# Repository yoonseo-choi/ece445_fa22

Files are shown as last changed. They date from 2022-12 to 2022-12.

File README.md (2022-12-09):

# ECE 445 Fall 2022 - Team 23

**Team Members**
- Yoonseo Choi (yschoi4)
- Aaron Gros (aygros2)
- Sean Kim (sk5)

**Lateral Movement Force-Feedback VR Gloves**

We have created a low-cost and open source force-feedback VR glove for lateral finger movement. It is able to acurate track and restrict the index, middle, ring, and pinky finger.

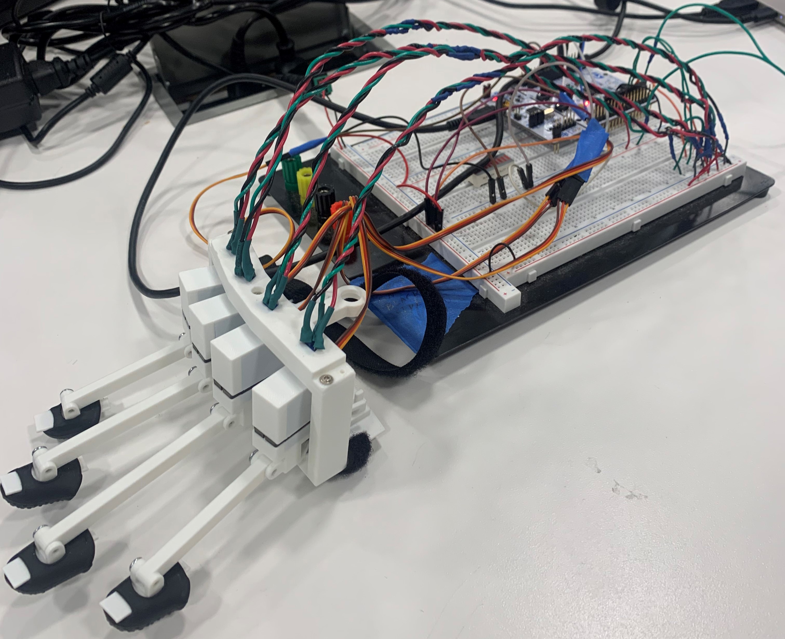
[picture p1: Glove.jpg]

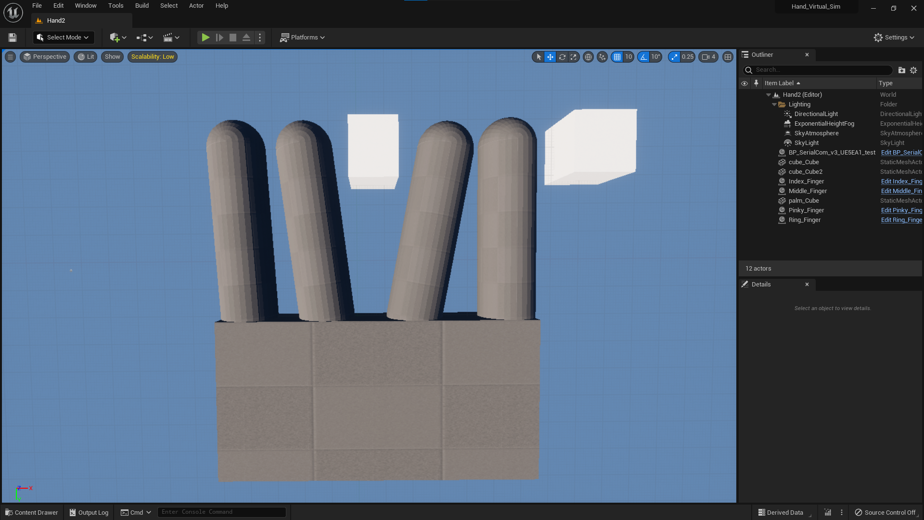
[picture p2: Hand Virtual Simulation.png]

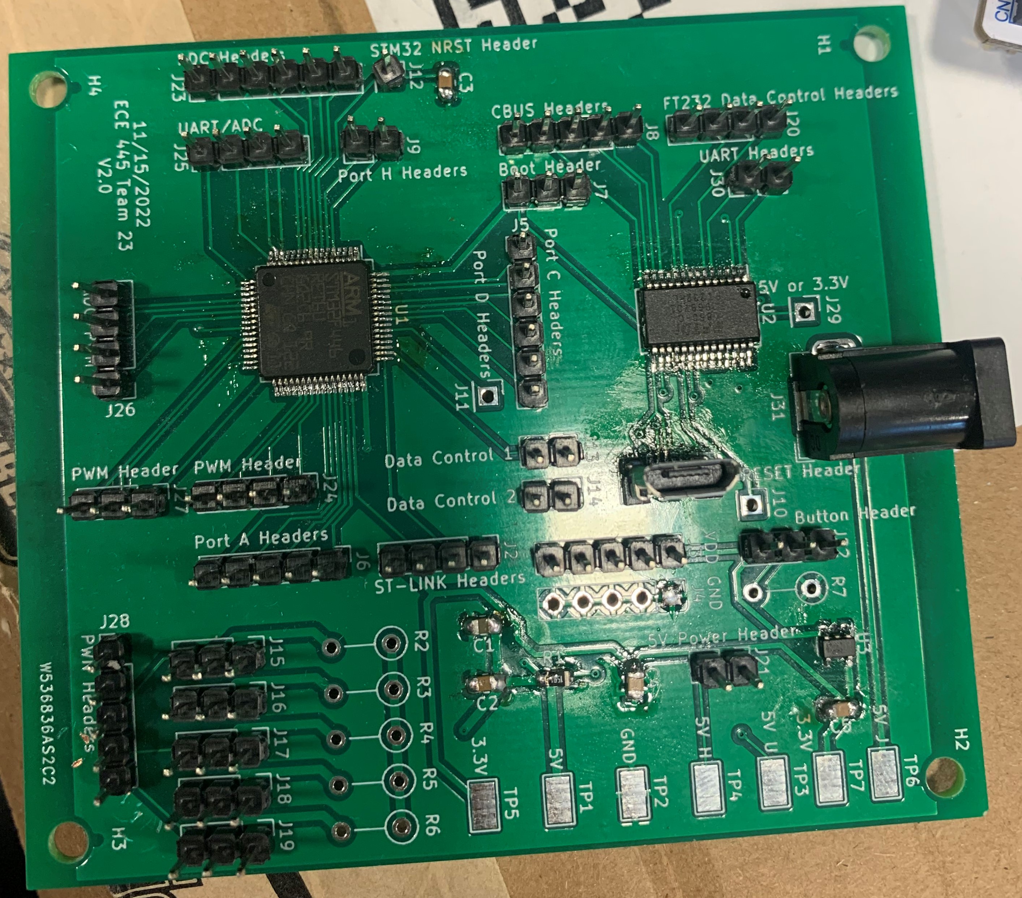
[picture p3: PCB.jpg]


**Google Drive Repository** 
[Google Repo Link](https://drive.google.com/drive/folders/11H3rUvDkAtsJpdgwuR88esnsnRXGqsm2?usp=sharing)

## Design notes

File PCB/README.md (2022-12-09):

# PCB 

**PCB Design for VR Glove**

This branch contains all files and folders related tothe pcb layout and design of the VR glove.

**Basic Git Commands**

1. git checkout pcb ; for switching into pcb branch

2. git pull ; get updated version of remote repo

3a. git add {whatever file you want to add} ; adds specific files

3b. git add . ; this adds all the changes you made

4. git commit -m "{whatever message}"

5. git push ; to update the remote repo

git status ; to check status of branch

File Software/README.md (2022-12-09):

Only uploaded the project content since the entire unreal engine project was too large. If you want to run this you need unreal engine 5.0.3 and you'll need this plugin: https://github.com/videofeedback/Unreal_Engine_SerialCOM_Plugin/. You'll have to create a project, import all the content and insert it into the scene. The colision option may reset so you may need to set the colision option for the fingers to BlockAllDynamic.

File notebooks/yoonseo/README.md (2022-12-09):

# Yoonseo's Notebook

**09-27-2022: Part Selection and Firmware Brainstorming**  

Decided on using servo motors for lateral movement feedback. 
Design is up for 2 options:
- Fixed pole and rotating restriction prongs
- Rotating (Side-to-Side) pole and fixed restriction prongs

Updated firmware data processing and control algorithm flowchart.

Ordered Stm32 MCU

**10-04-2022 PCB Design Parts 1**

Decided on Micro-USB, ST-Link, FTDI Parts

Started crafting the PCB design after design review today

Design review critiques:
- Tolerance Analysis: more specific with angle precision (data value count / rotation angle degree)
- Safety: Be cautious about the servo motor torque on finger and show calculations assuring its safety.

Need to decide if we want to use CTS and RTS flow control scheme for FTDI <-> STM32 MCU

**10-08-2022: PCB Design Parts 2**

Completed the micro usb module that functions as power and usb data communication (still need to annotate fuse value)

Added basic connections for both STM32 and FT232 chip
- STM32: figure out how to use connectors on pin PA13,14 for SWD ST-Link Programmer
- FT232: Need to decide how to route other pins (i.e. NRESET, CTS, RTS, etc) and add male connectors to GND and VDD

**10-14-2022: Parts Ordering**

Completed a list of the project's BOM and started ordering the physical parts for the PCB.

Initiated a project folder on STM32 Cube IDE for the development of STM32F446RE firmware

**10-22-2022: Stm32 Development Board Testing**

Before moving everything over to our PCB, we decided to develop and test all of our firmware features on the STM32F446RE development board

Spent much time on the MCU documentation learning the specifications of the ADC channels, PWM timers, and UART communication protocols. 

Some setbacks:
- Assigning pins for each of the modules proved to be challenging since I had to make sure the pins I was using did not overlap in functionality of other relevant functionalities. 
- Setting an appropriate clock configuration (fast enough clock speed)

**10-29-2022: PCB v1.0 Order & Dev Board UART Configuration**

Made final changes to the PCB v1.0 order.

Aside from that, I continued my work on the firmware, specifically on the UART. 

All code I used for this project relied on the given HAL libraries. To see if I was sending the correct data to the PC, I configured the minicom serial monitor on my computer (running on Ubuntu) so that the HAL_UART function printed to the console.

**11-07-2022: PCB v2 Start & ADC Channel Configuration**

For our PCB v1.0, we realized a crucial mistake: not recognizing the correct operating voltage of MCU. 

Essentially, we fed 5V into a 3.3V system. Consequently, we fried our MCU, and since it took over a month for it to arrive, we decided that ordering another STM32 (from china) would be pointless given the current lead time.

To address this problem, and some other power problems, we determined using a higher power rating wall plug and a 5-3.3V Linear Converter would be new additions for our next PCB.

As for the firmware, I was able to start development for the ADC channels in order to sample the potentiometer voltage values from the finger movements. 

ADC Configuration Challenges:
- Needed to prioritize order of channel sampling and sending them to pc via uart
- Decided to utilize DMA mode for ADC for more efficient CPU cycle use

**11-12-2022: PWM Timer Configurations**

The servos we ordered required specific pwm signals to rotate certain angles.

When setting the configurations for PWM, there were many calculation to be made and setting/modifying control register to specific values.

PWM Timer Register Configuration

[Servo Motor Data Sheet](../../MG90S_Tower-Pro.pdf)

**11-13-2022: PCB Soldering and Firmware Algorithm Development**

Our parts for the PCB arrived, so we soldered on all of our parts except the STM32. At this point, since we only had the MCU on the dev board, we determined that waiting to place the MCU on the custom PCB after testing the firmware to its full functionality would be the optimal decision.

Hands down, the hardest part about the algorithm development was determining the correct pulse to send to the servo and the angle it should turn to accurately restrict the finger movement of the user. 

This session aimed to mostly cover the moving of the servos to the desired angle and create functions to do so. 

**11-25-2022: FW Algorithm Testing and SW Integration**

After thanksgiving, I was able to finish the initial firmware draft and start testing the actual glove with different stimuli. After I was able to verify some of the controls requirements for our project, I started to create a standard data format where to get ready for the graphics platform to communicate under a similar data scheme with the firmware.

Out Data: (16 bytes) 4 bytes for each finger position
In Data: (4 bytes) 1 byte for each finger using 2 bit representation
- '0'(00): no collision
- '1'(01): right collision
- '2'(10): left collision
- '3'(11): both collisions

We made videos of the project successfully performing requirements set, then soldered the STM32 onto the custom PCB

**12-01-2022: Final Demo Review**

Our last meeting for the development process was making sure we had all the verification for our requirements, rubrics printed out for the demo, and last minute checklist run down. Although we weren't able to demo today with our actual product (because the custom PCB didn't work), we were able to show videos of the working glove. It was a huge regret not being able to showcase what I've worked on the whole semester with so much time and effort, but it proved to be a valuable lesson where it taught me that there are always priorities and when you run into a dilemma, choosing one way will always have some consequences for not choosing the other, but you still need to make the best out of it and weigh your pros and cons before settling on a single decision.

Overall, this project taught me many things about not just the firmware development of the STM32 but also time management, project insight, team communication, etc. It'll be skills I'll continue to develop throughout my career.

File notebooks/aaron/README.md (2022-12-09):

10/17/2022

**Objective:** Get started 3d modeling all the pieces

**Accomplished:** Designed a base that stays in place on one’s hand with velcro straps. It also had bearing holders and stopping pins. I got a 3d model of the servo we’re using online. I made a model for our bearing and potentiometer based on dimensions I found where I ordered them. I made two pieces that go on the top and bottom of the servo and attach to bearings. I designed a piece with bearing holders that attaches to the base and holds the servo in place. I designed a piece that goes over the previous piece and holds the potentiometers. I made an extension to the servo arm that interacts with the stopping pin.

<p float="left">
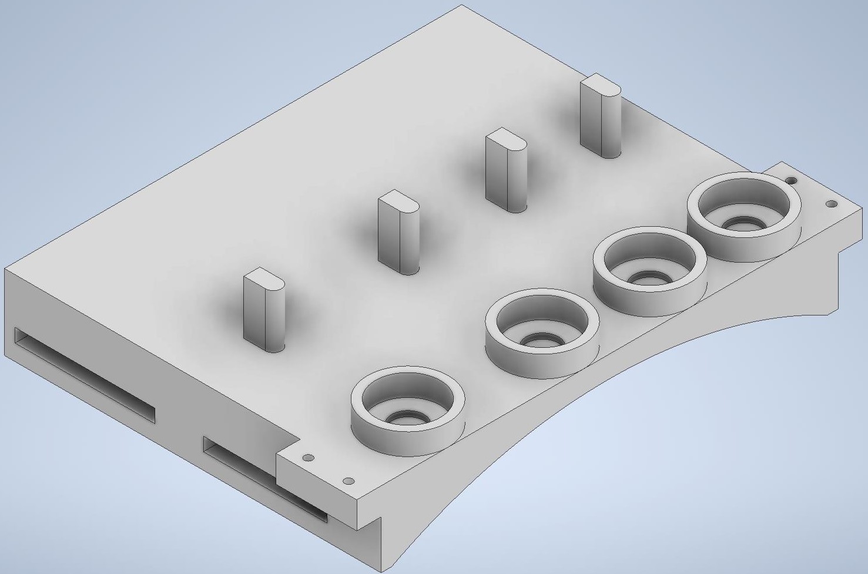
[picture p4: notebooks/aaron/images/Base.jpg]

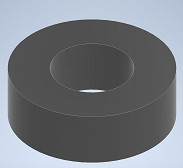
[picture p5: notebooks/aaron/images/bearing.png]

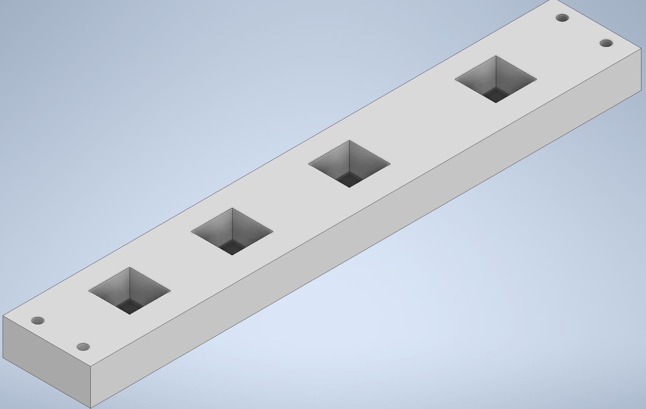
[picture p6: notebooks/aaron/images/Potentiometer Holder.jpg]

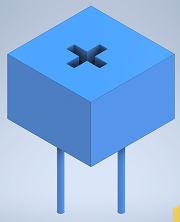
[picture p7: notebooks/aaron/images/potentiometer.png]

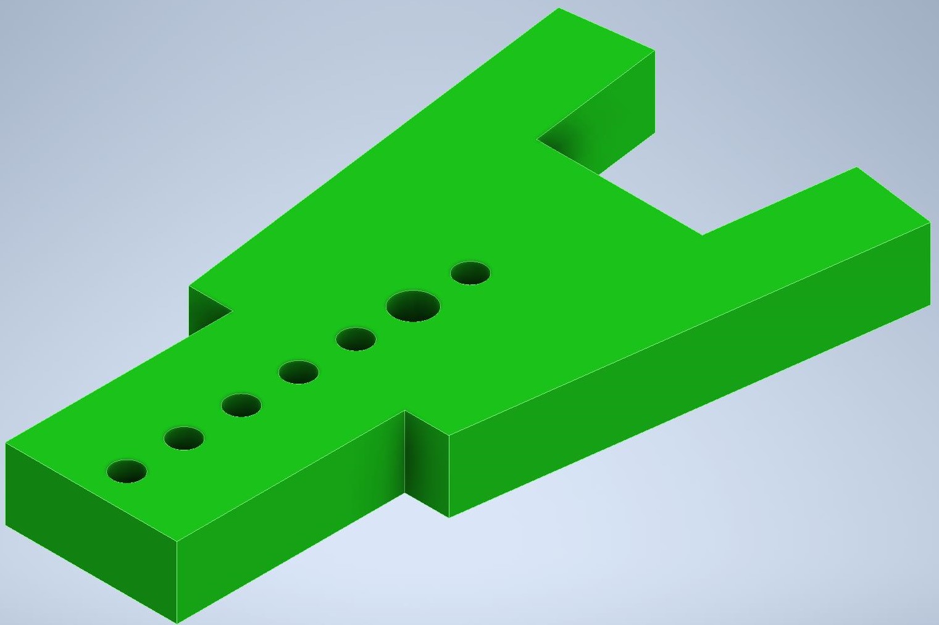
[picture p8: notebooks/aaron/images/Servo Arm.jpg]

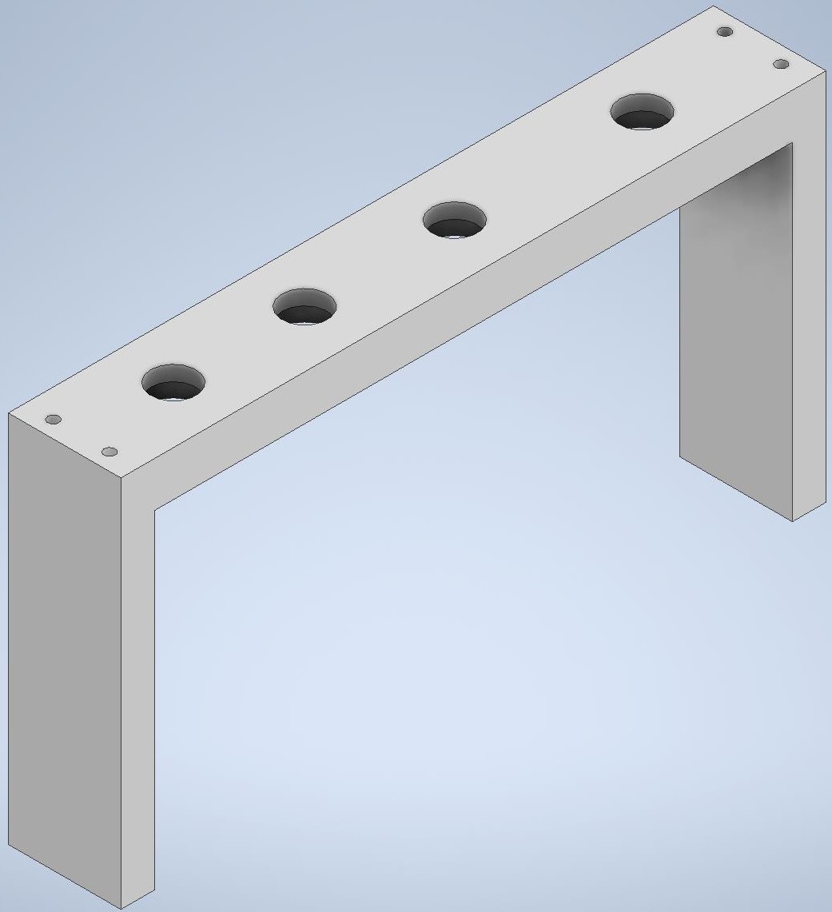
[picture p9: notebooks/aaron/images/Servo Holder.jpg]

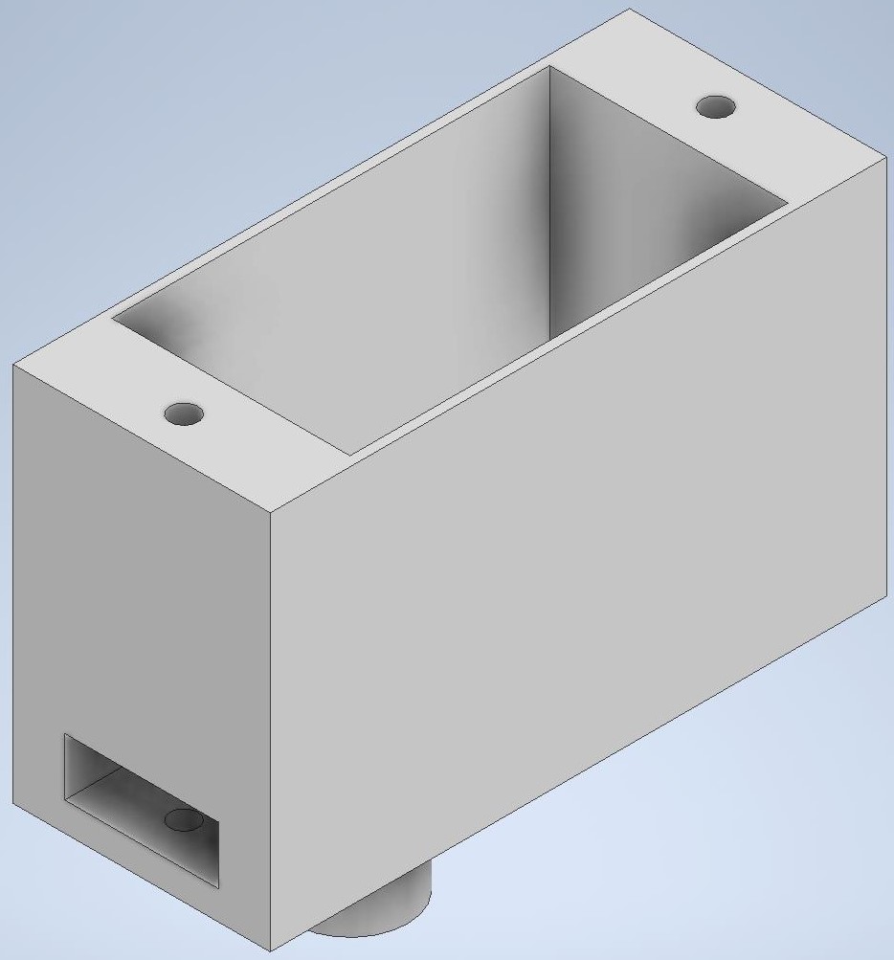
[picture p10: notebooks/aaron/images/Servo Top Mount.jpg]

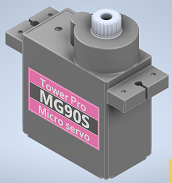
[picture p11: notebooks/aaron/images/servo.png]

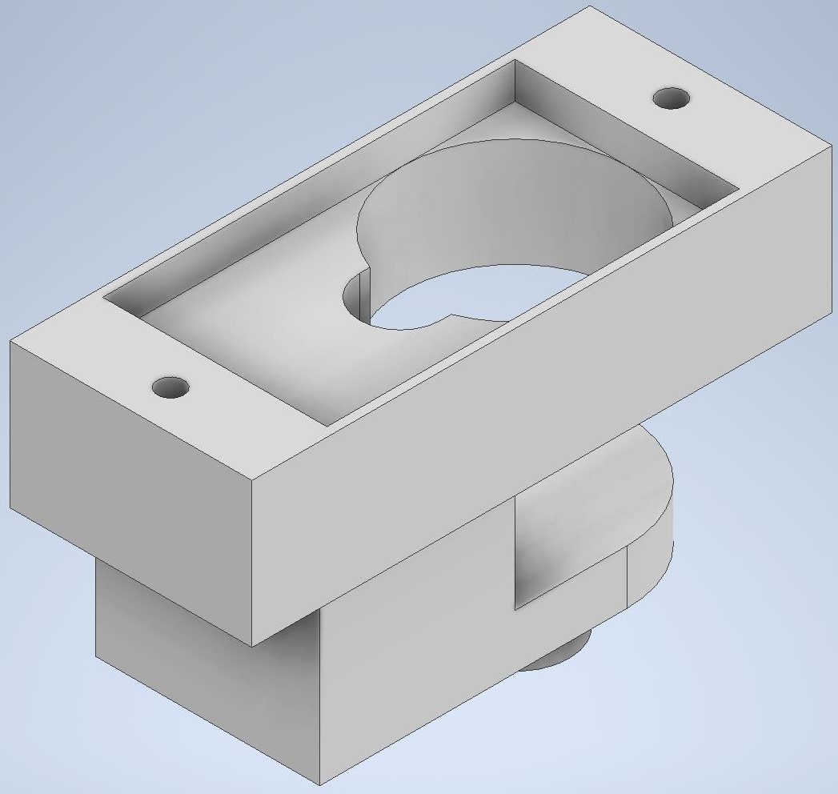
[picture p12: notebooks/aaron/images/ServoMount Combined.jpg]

</p>

---

10/24/2022

**Objective:** Separate the previous 3d models into pieces that have as few overhangs as possible to simplify the printing process in case the previous models can’t be printed. Make an assembly of all the pieces.

**Accomplished:** I separated the pieces as best I could to avoid overhangs, and I made an assembly of most of the pieces.

<p float="left">
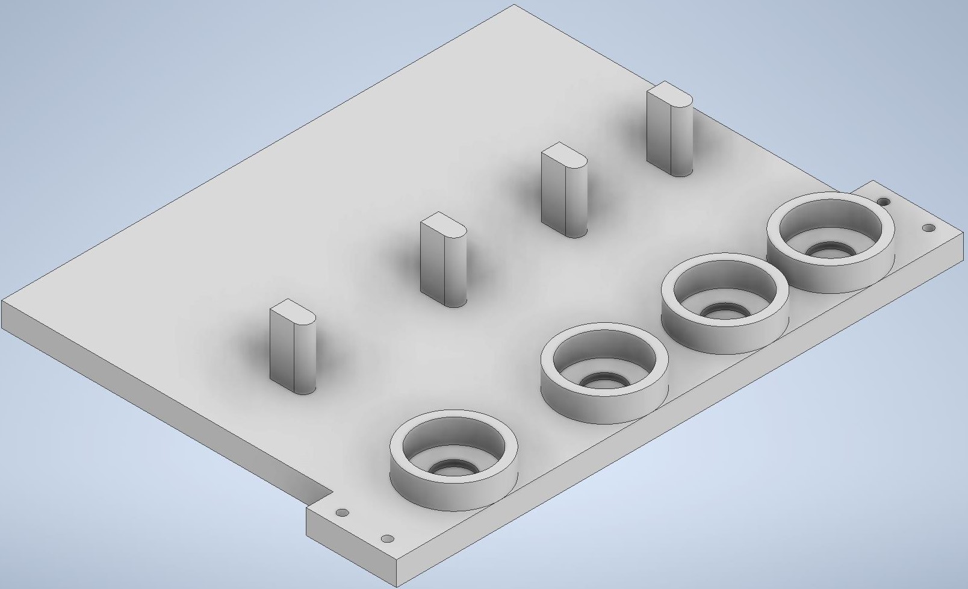
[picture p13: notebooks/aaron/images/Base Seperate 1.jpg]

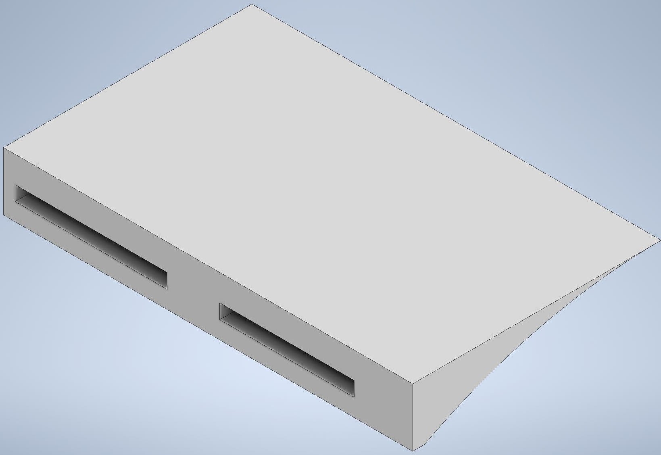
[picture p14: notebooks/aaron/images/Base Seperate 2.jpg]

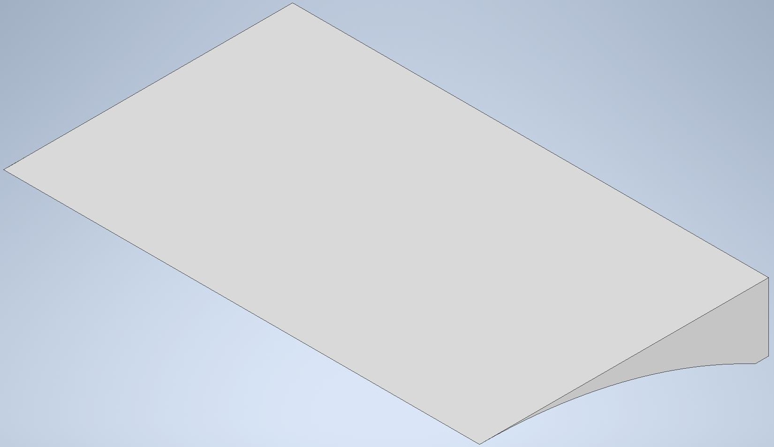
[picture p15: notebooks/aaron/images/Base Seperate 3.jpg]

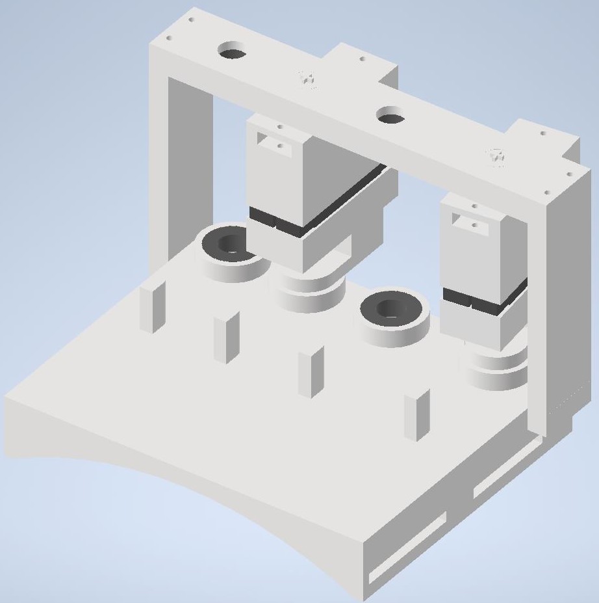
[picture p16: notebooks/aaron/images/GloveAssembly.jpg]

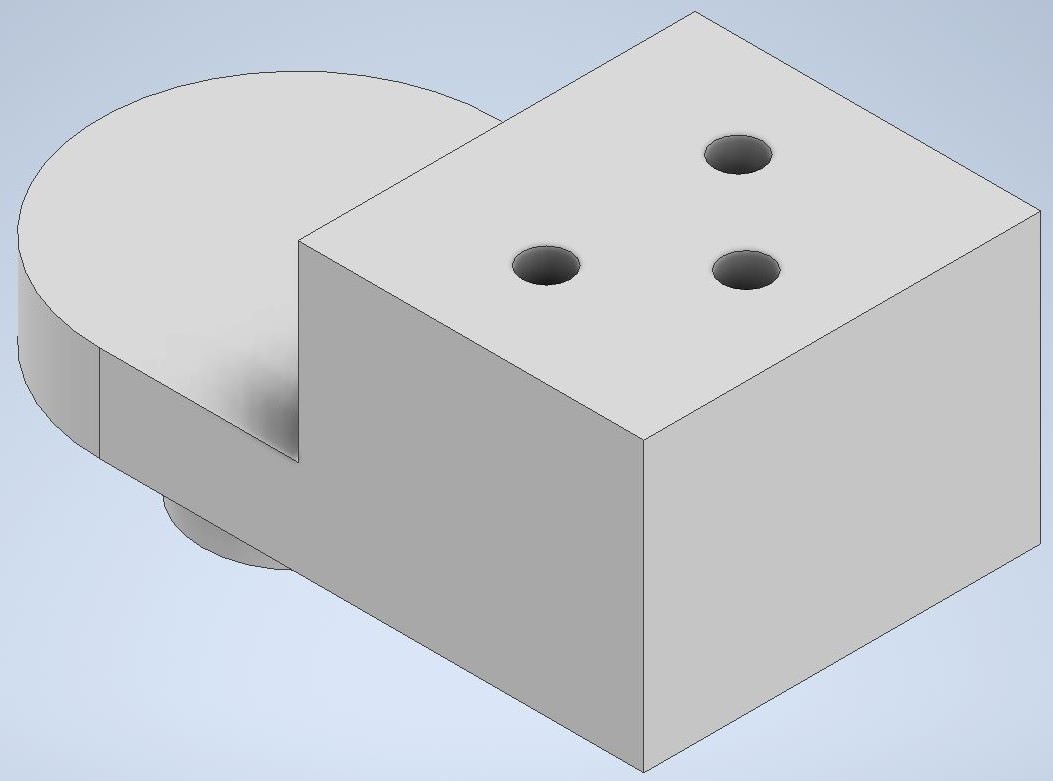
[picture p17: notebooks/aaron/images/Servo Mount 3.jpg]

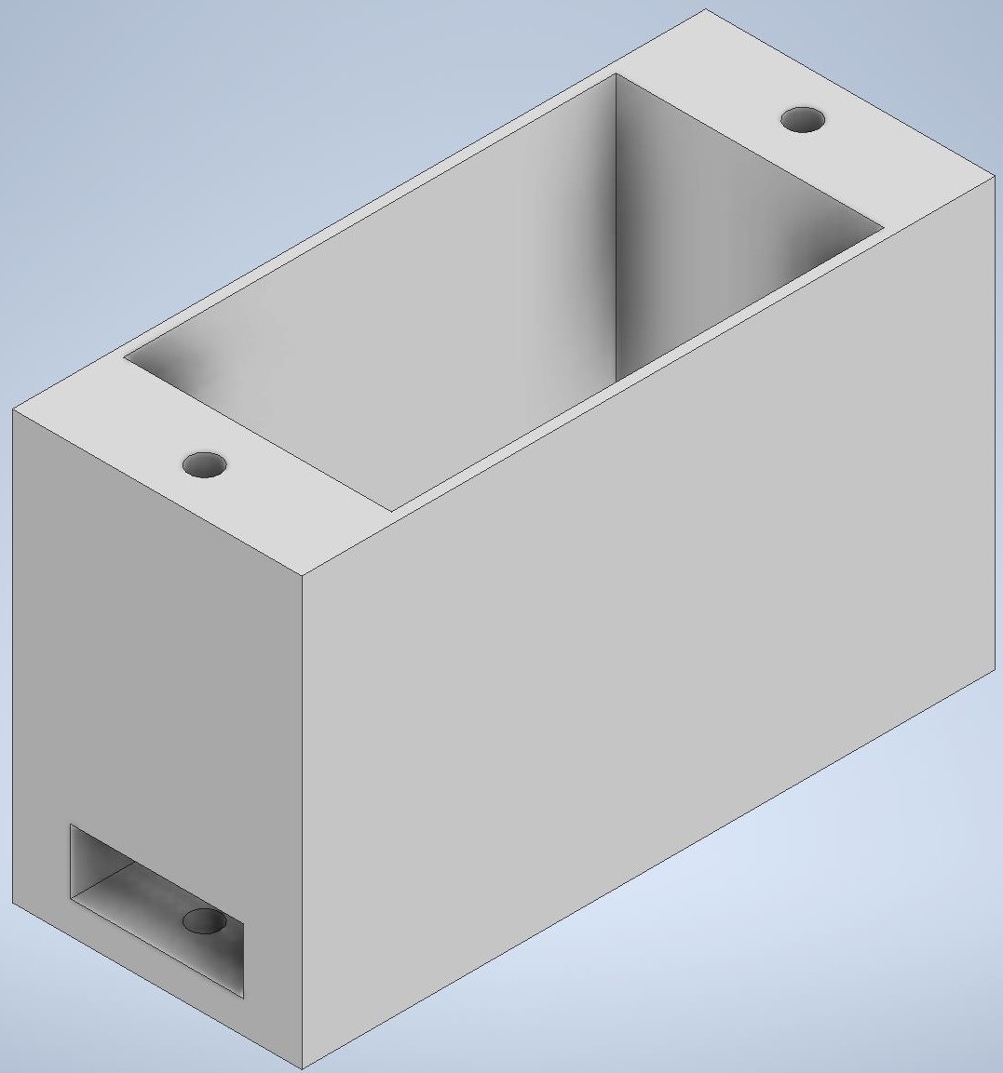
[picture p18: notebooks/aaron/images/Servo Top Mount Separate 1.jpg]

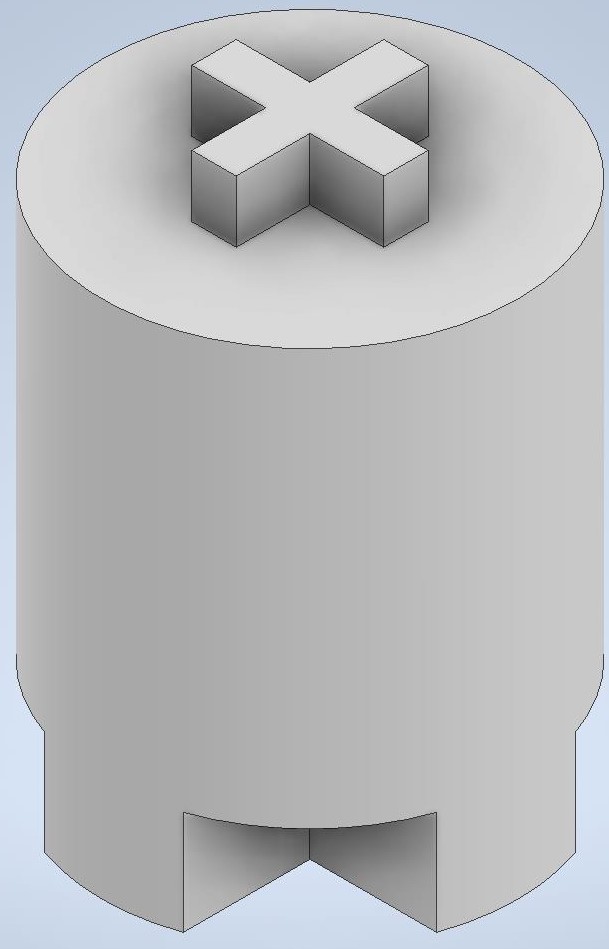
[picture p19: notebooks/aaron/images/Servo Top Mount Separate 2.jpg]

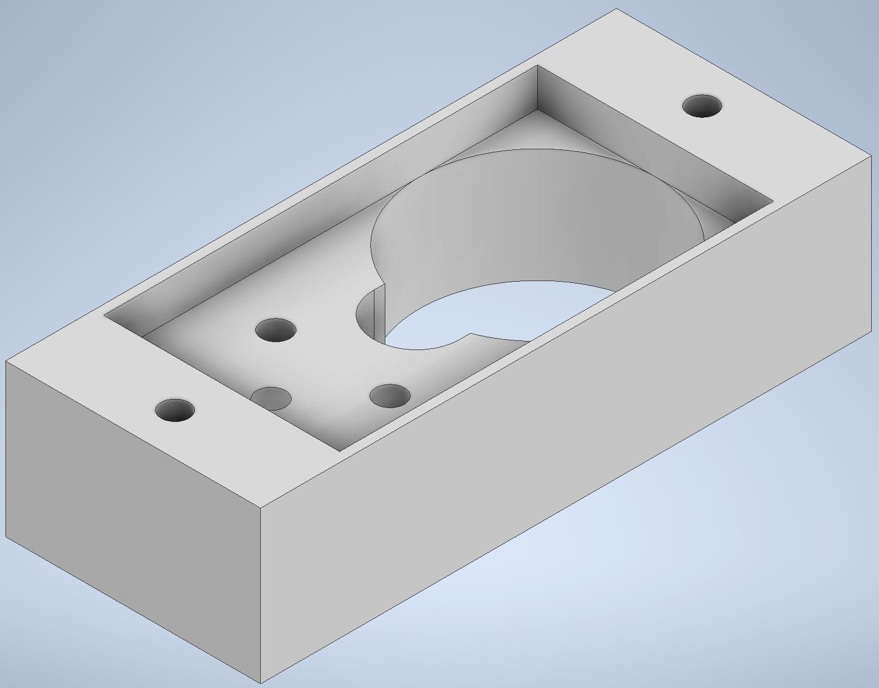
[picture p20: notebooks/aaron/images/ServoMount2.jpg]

</p>

---

11/4/2022

**Objective:** Print all the pieces

**Accomplished:** I finally got the 3d printing filament and access to a 3d printer so I was able to print all the pieces to test them. The base feels uncomfortable and probably needs to be redesigned but the rest seem pretty good.

---

11/7/2022

**Objective:** model base and affected parts after an image on my hand to make it fit better. Modify servo arm to only require one screw. Find out the right size for bearing holders and inserts, as well as screw holes.

**Accomplished:** redesigned the base, potentiometer holder, and servo holder to follow the shape of my hand since the last design felt pretty uncomfortable and didn’t alight very well with the joints. I also added guard rails on the servo arm so that I can only use one screw without having the servo arm slider around. Lastly, I tested several pieces to find the right size for the bearing holders and inserts, and to find the right size of screw holes.

<p float="left">
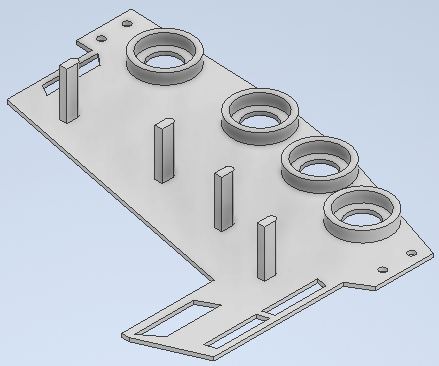
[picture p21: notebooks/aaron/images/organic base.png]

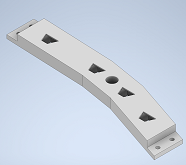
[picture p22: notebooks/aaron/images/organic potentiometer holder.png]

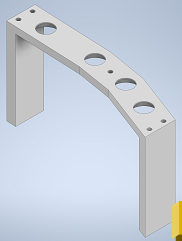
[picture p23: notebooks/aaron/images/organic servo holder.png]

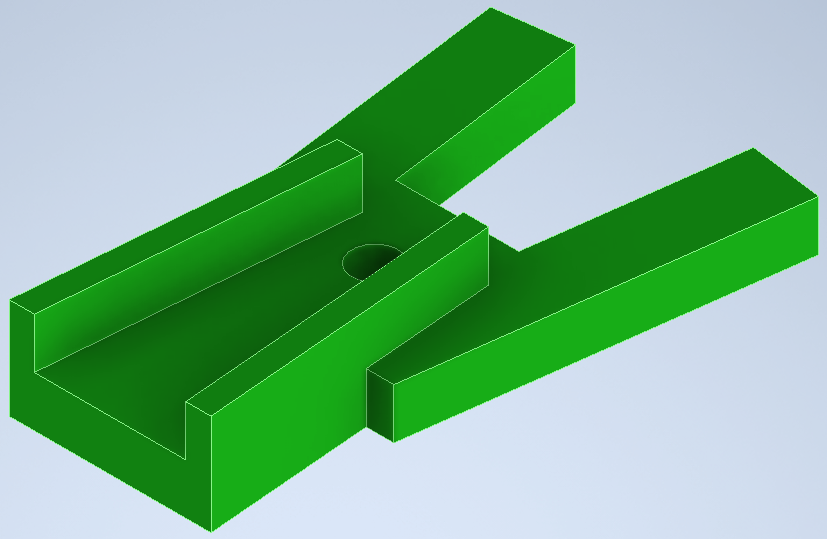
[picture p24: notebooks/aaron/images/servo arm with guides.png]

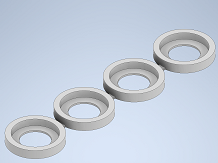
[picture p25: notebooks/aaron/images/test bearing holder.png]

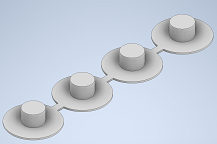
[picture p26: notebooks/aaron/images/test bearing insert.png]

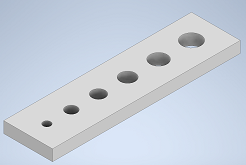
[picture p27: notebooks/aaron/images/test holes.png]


</p>

---

11/8/2022

**Objective:** Find some guides on how to get started

**Accomplished:** Found a guide to rotate an object: https://www.youtube.com/watch?v=NXbJPScS5fI. 
And a guide to setup serial communication: https://www.youtube.com/watch?v=ElM9EQVjR-8 

---

11/10/2022

**Objective:** To implement serial communication following this guide: https://www.youtube.com/watch?v=ElM9EQVjR-8 

**Accomplished:** I got serial communication to work and it reads serial when I press space. However, I need to add a way to parse the data to extract just what I need. Here’s an image of the current unreal engine blueprint



---

11/12/2022

**Objective:** To add a way to switch ports while the program is running, and to parse the data to be able to extract the potentiometer values.

**Accomplished:** I added port switching by ‘w’ or ‘s’ to go up or down a port, respectively. I also got the data parsing to work. I ended up having to set up a buffer that I add the serial data to since every iteration I only read part of the serial message. I also added delimiters to know where the beginning and end of the packet is, and added ‘,’ in between each potentiometer value to be able to parse those. Below is the updated unreal engine blueprint.



---

11/13/2022

**Objective:** Want to make an object in unreal engine that can be rotated and that stops rotating when it collides with an object.

**Accomplished:** Made a rectangle that I could rotate left or right by pressing ‘g’ or ‘h’, respectively. I haven’t been able to get it to sense collision so it just goes inside other objects. I’m not sure if it’s because I’m using a static mesh and maybe I should be using a skeletal mesh. Below I show how the rectangle ends up overlapping the other rectangle.



---

11/15/2022

**Objective:** Increase the servo arm degrees of freedom. Add extra space between the pinky and ring fingers. Add extra space between bearing holder and servo holder legs. Add a way to attack the bottom servo mount to the fingertip.

**Accomplished:** modified the base, potentiometer holder, and servo holder to add extra space on the side of some of the bearing holders. Gave the stopping pins offset heights to offset the orientation of the servo arm allowing for more degrees of freedom without hitting each other. Also widened the servo arm to achieve this. The stopping pins end up bending under load, and the finger exoskeleton isn’t the right length. 

<p float="left">






</p>

---

11/17/2022

**Objective:** Figure of how to get static meshes to sense collisions or switch to a skeletal mesh. Get the mesh to stop rotating when it collides.

**Accomplished:** I got the static mesh to sense collisions and stop rotating when it hits another object. The issue was that I had the wrong collision preset selected on both the objects. Below I show the mesh stopping when it collides.



---

11/20/2022

**Objective:** add removable potentiometer key to servo top mount, fix finger tip, add button mount, find right finger exoskeleton length, and adjust base stopping pin offset heights.

**Accomplished:** Printed several test pieces to find the right size for the removable potentiometer key and its hole. Made a less flimsy finger tip piece. Found the right length for each finger exoskeleton piece. Added a latching button mount to the potentiometer holder. Adjusted the offset heights of the stopping pin on the base and added a piece connecting the bearing and stopping to prevent the stopping pin from bending.

<p float="left">







</p>

---

11/22/2022

**Objective:** Make a two mesh that can rotate together but have independent left and right collisions. Add the serial communication from before to control the rotation angle.

**Accomplished:** I made a left and right hand finger model in blender and imported them into unreal engine. I was able to make the both meshes part of the same object by adding both of them to a blueprint class. They are able to rotate together and sense collisions on their corresponding side. Getting the meshes to rotate took longer than I expected because the angels became negative so I had to do some math on the angle before using it. I also got the serial data to control the rotation and added serial output notifying of collisions. Below is the finger mesh in unreal engine next to a box it collides with, there also an image of the blueprint for the finger blueprint class

<p float="left">


</p>

---

11/23/2022

**Objective:** To take the individual working finger and copy it to create a hand without the thumb.

**Accomplished:** Made the hand without the thumb, the collisions on each finger are working correctly, and they are all controlled with the serial data.



---

11/27/2022

**Objective:** Integrate the firmware with the virtual simulation

**Accomplished:** Adjusted some issues in the serial data parsing. Calibrated the firmware based on the physical glove, and calibrated the virtual simulation based on the firmware. Got the entire project to work together on the dev board. Had to angle the potentiometer to avoid an area of the potentiometer that wasn’t working. Below is the physical glove connected with the dev board which is connected to the computer, and an image of the angled potentiometer key.

<p float="left">


</p>

---

12/08/2022

Worked on the presentation, and final report this week.

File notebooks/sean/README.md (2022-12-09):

# Sean's Notebook

## 09-22-2022

Had a meeting with the team to brainstorm about what part to use for lateral movement feedback.
2 part options we came up with:
- servo motors (we haven't figured out how we will modulate motors)
- magnetic friction brakes (haven't found a part that would fit fot our design)

Did some research on the parts I've mentioned and found a few different products

## 09-27-2022

Our team decided on using servo motors for lateral movement feedback after more research and having some talk with TA.

We ordered STM32 MCU

## 10-03-2022

We finalized our parts list and started ordering them.

Yoonseo and I started working on the schematics.

## 10-08-2022

Finished the schematic.

version1_schematic

## 10-09-2022

Started working on PCB design.

Problems:
- so many tangled connections near the MCU (since pins of the MCU are facing all four ways)
- the PCB still has too much unused space

Solutions & things I learned:
- to untangle all unconnected ones, I decided to use some vias (solved the congestion near the MCU
- I found out that wires can go through parts when there is no connecting pins. previously I thought I have to go around all parts which led me to have so much empty space left

## 10-14-2022

Finished designing PCB

version1_pcb

I learned how to order our PCB from PCBWAY website and how to generate gerbers.

## 10-16-2022

My teammates and I realilzed that some of the components were not available to order and also we had to use a different micro-USB for our second round PCBway order

## 10-28-2022

Aaron picked up our version1 PCB.

pcb_1

## 11-01-2022

Assembled PCB

## 11-17-2022

We realized that we need a linear voltage regulator to drop down 5V to 3.3V for MCU

## 11-18-2022

Added a linear voltage regulator to our PCB.

Also added a few more testpads and some pin holes for later use.

Connection for the barrel jack is also added to the design for our 5V power input.

Version2 PCB done.

version2_pcb

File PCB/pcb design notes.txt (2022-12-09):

will use a via to connect all components need connection with
usb-u (U1_pin4). we can use the back side of the board

J15_tim2_ch2 needs to be connected to U1_pin55 through a via
or just a longer route

stm32 pin layout: (1~16), (17~32), (33~48), (49~64)
	should we split J5, J6, and J7 into more headers?
	this would clean up the pcb layout much better

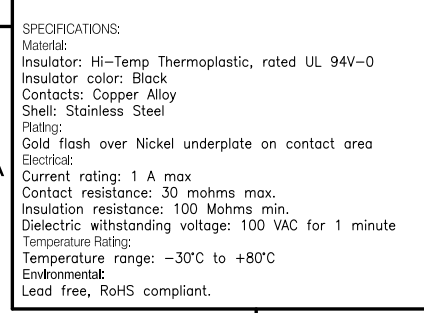
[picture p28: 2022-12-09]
PCB/mcr-b-s-ra_specs.png

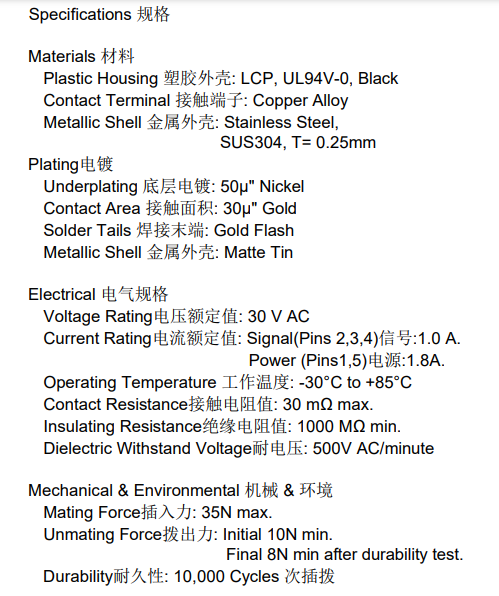
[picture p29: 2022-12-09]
PCB/USB3075_specs.png

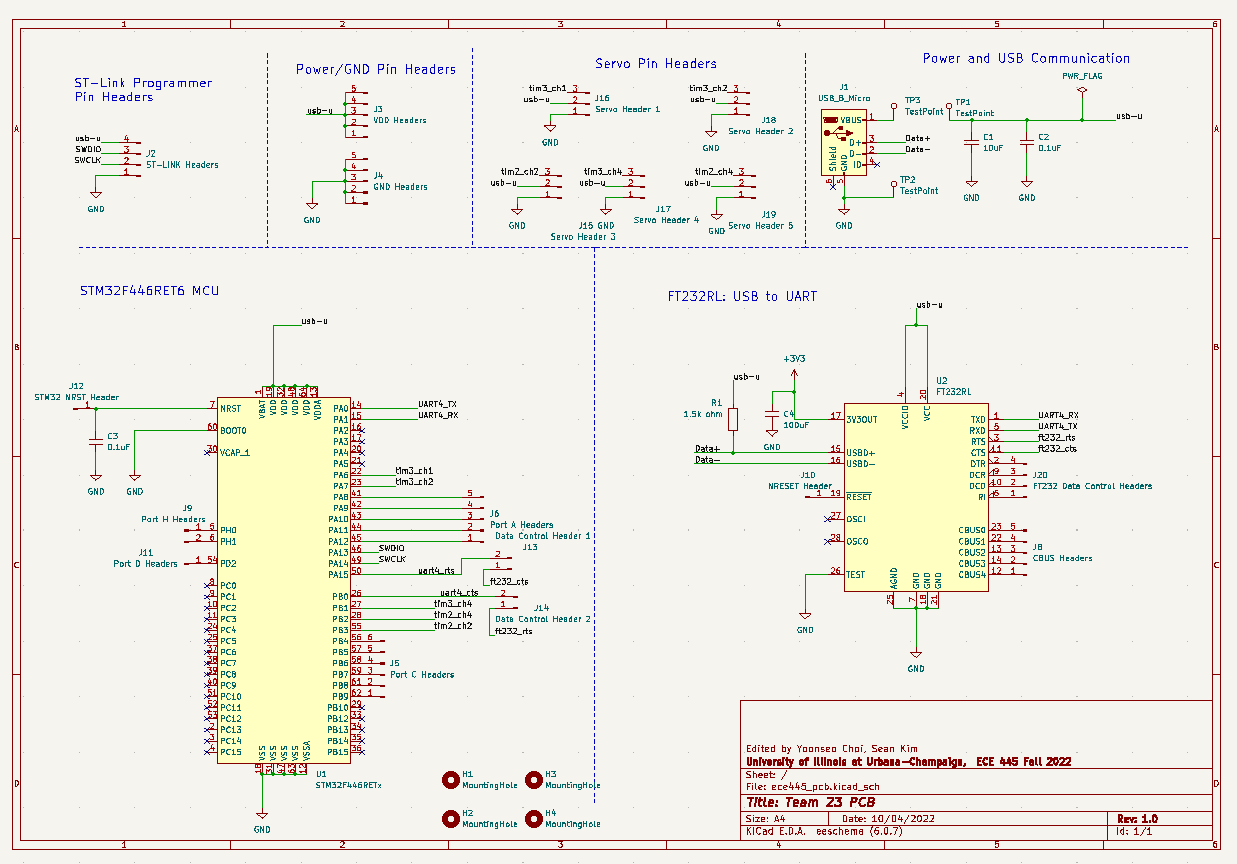
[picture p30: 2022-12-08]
notebooks/sean/version1_schematic.png

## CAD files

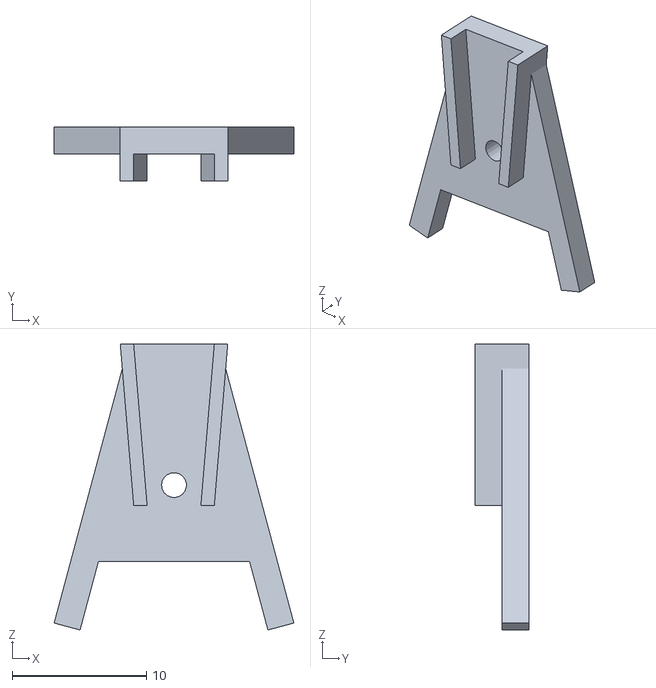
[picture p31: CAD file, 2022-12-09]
Machanical/stl files/Servo Arm.stl
17.8 x 4.00 x 21.3

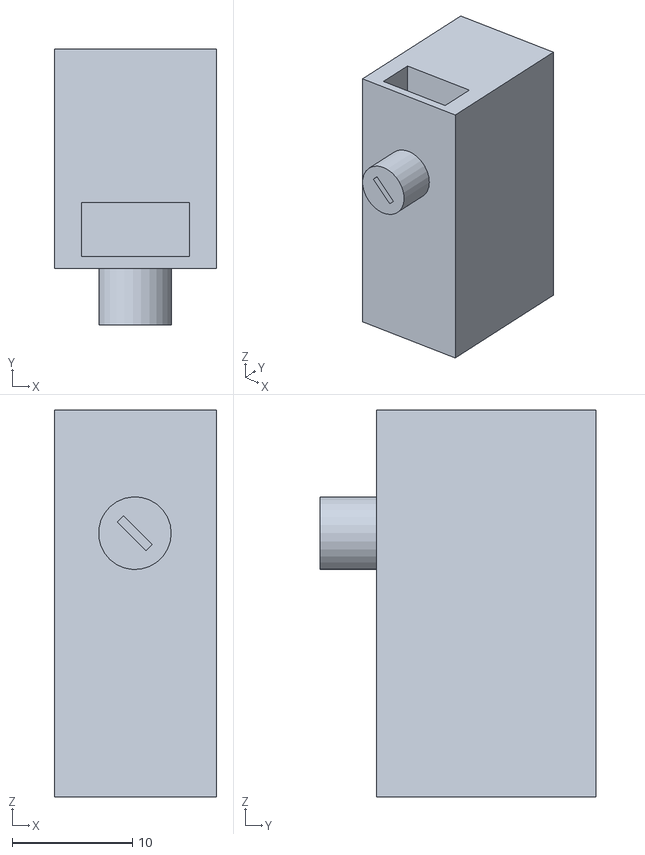
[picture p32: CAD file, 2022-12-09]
Machanical/stl files/Servo Top Mount.stl
13.5 x 23.0 x 32.2

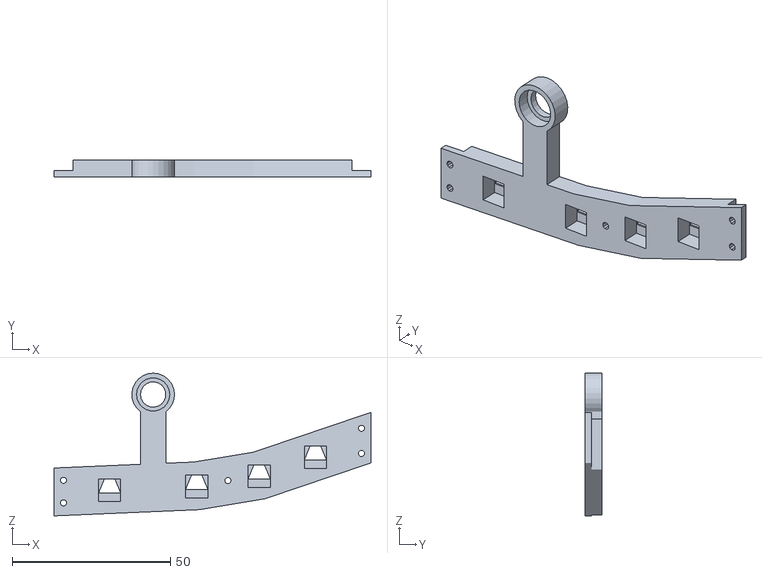
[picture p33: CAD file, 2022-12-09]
Machanical/stl files/Potentiometer Holder.stl
100.0 x 5.40 x 45.1

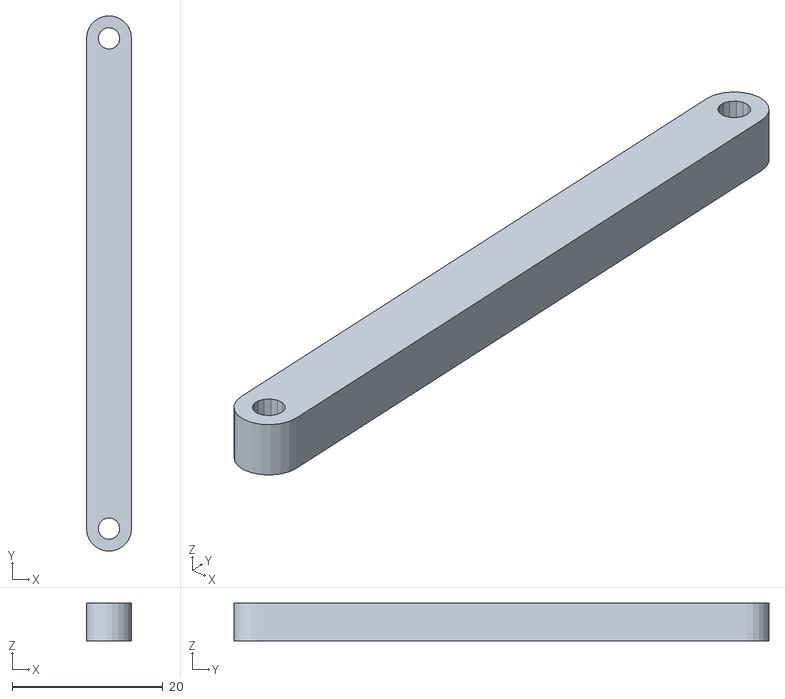
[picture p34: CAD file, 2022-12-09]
Machanical/stl files/Ring Finger Exoskeleton.stl
6.00 x 70.9 x 5.00

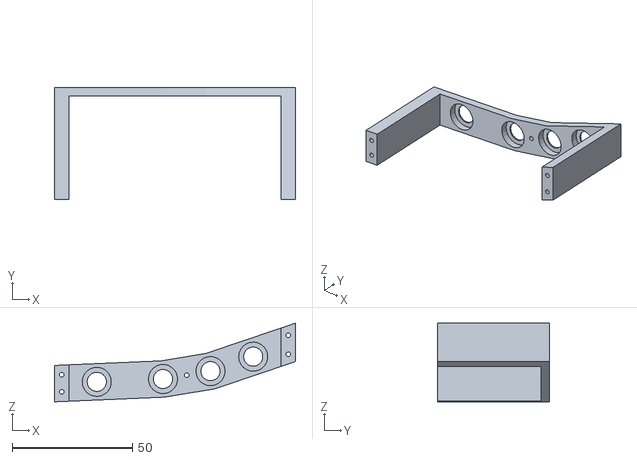
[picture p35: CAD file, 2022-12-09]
Machanical/stl files/Servo Holder.stl
100.0 x 46.5 x 32.7

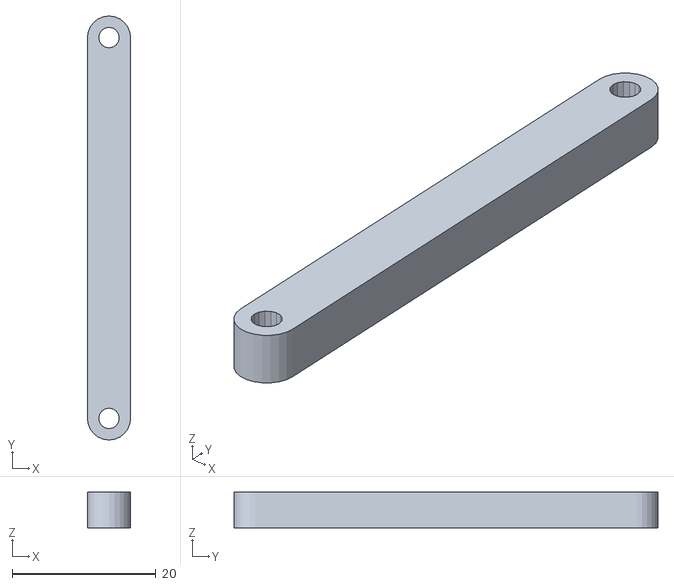
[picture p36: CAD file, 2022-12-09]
Machanical/stl files/Pinky Finger Exoskeleton.stl
6.00 x 59.0 x 5.00

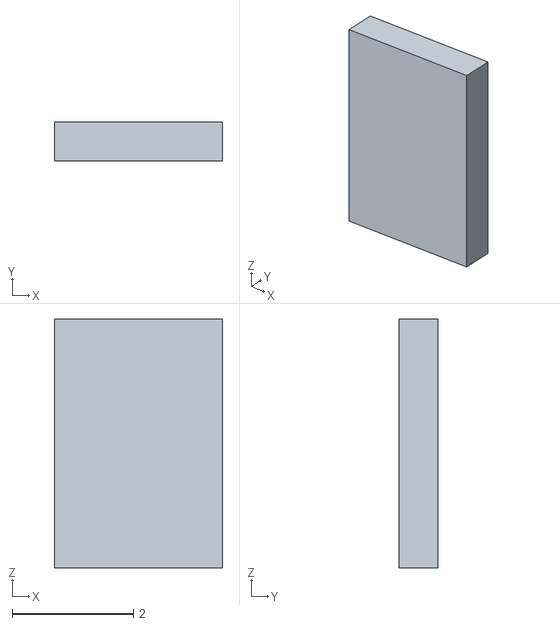
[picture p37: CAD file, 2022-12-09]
Machanical/stl files/Potentiometer Key.stl
2.77 x 0.64 x 4.10

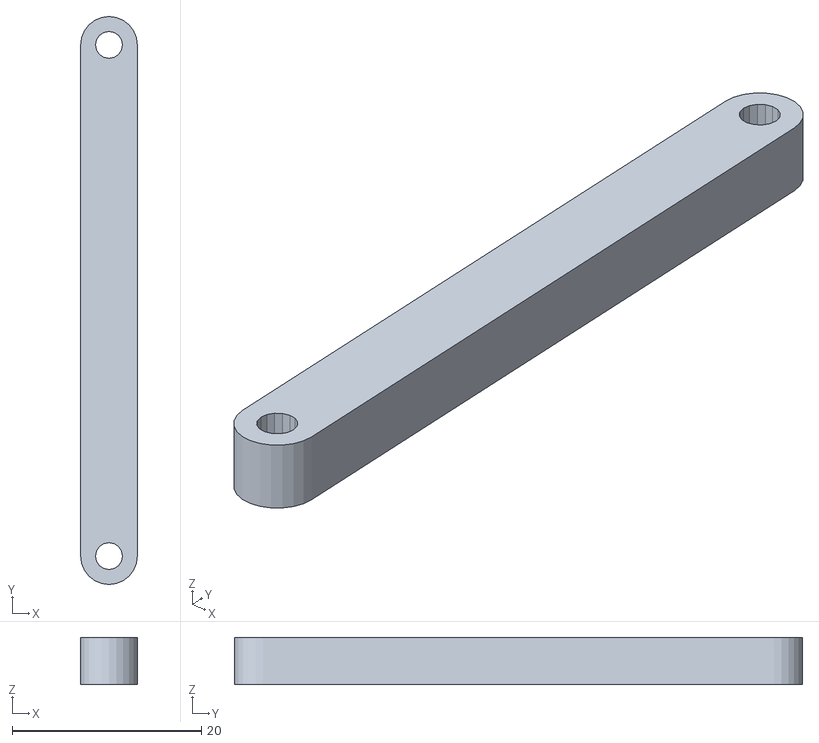
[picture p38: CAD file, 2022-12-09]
Machanical/stl files/Pointer Finger Exoskeleton.stl
6.00 x 60.0 x 5.00

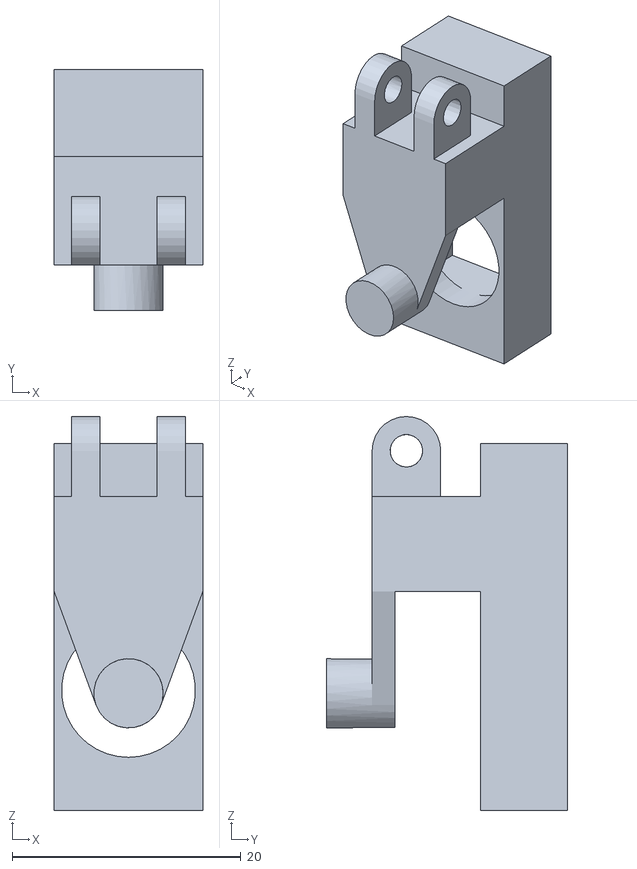
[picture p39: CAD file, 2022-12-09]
Machanical/stl files/Servo Bottom Mount.stl
13.0 x 21.1 x 34.4

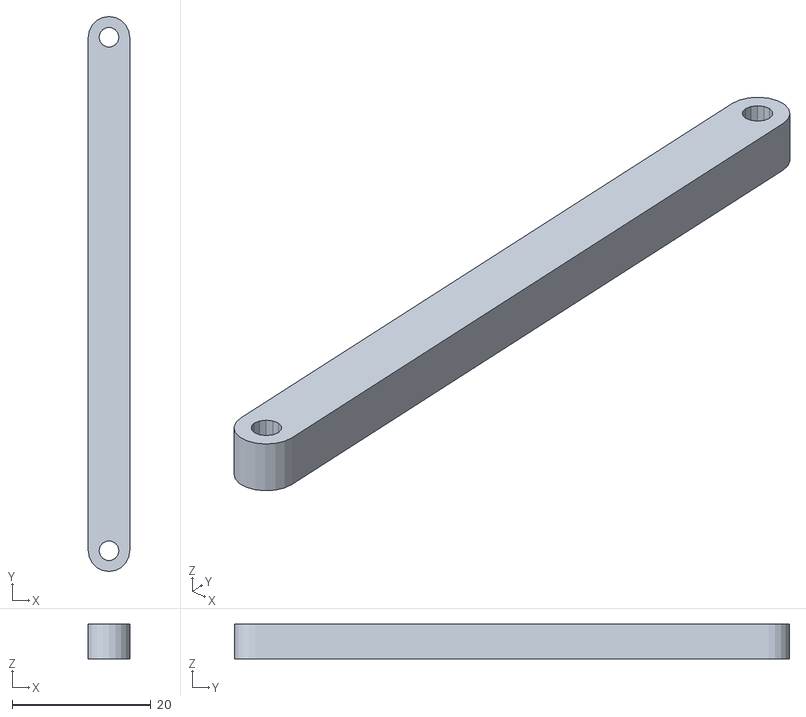
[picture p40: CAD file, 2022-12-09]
Machanical/stl files/Middle Finger Exoskeleton.stl
6.00 x 80.0 x 5.00

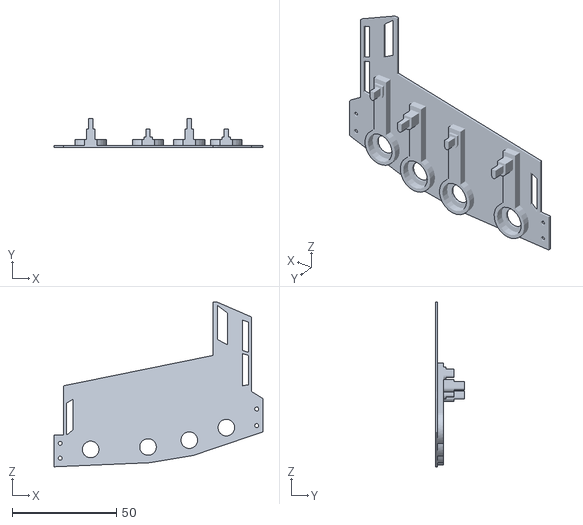
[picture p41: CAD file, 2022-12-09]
Machanical/stl files/Base.stl
100.0 x 14.0 x 78.8

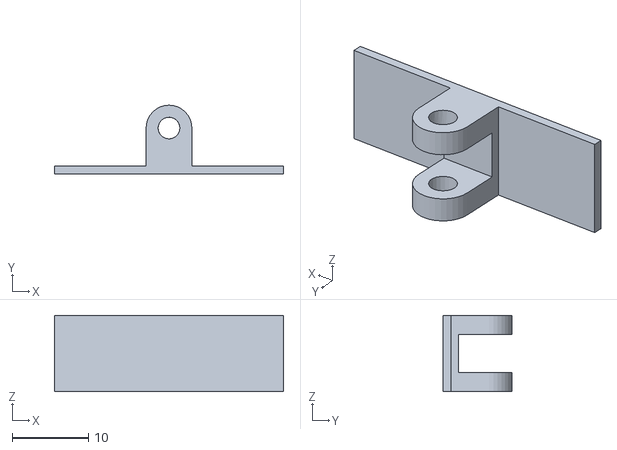
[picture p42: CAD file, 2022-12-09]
Machanical/stl files/Finger Tip.stl
30.0 x 9.00 x 10.0

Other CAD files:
Machanical/ipt files/Finger Tip.ipt
Machanical/ipt files/Middle Finger Exoskeleton.ipt
Machanical/ipt files/Pinky Finger Exoskeleton.ipt
Machanical/ipt files/Pointer Finger Exoskeleton.ipt
Machanical/ipt files/Potentiometer Holder.ipt
Machanical/ipt files/Potentiometer Key.ipt
Machanical/ipt files/Ring Finger Exoskeleton.ipt
Machanical/ipt files/Servo Arm.ipt
Machanical/ipt files/Servo Bottom Mount.ipt
Machanical/ipt files/Servo Holder.ipt
Machanical/ipt files/Servo Top Mount.ipt

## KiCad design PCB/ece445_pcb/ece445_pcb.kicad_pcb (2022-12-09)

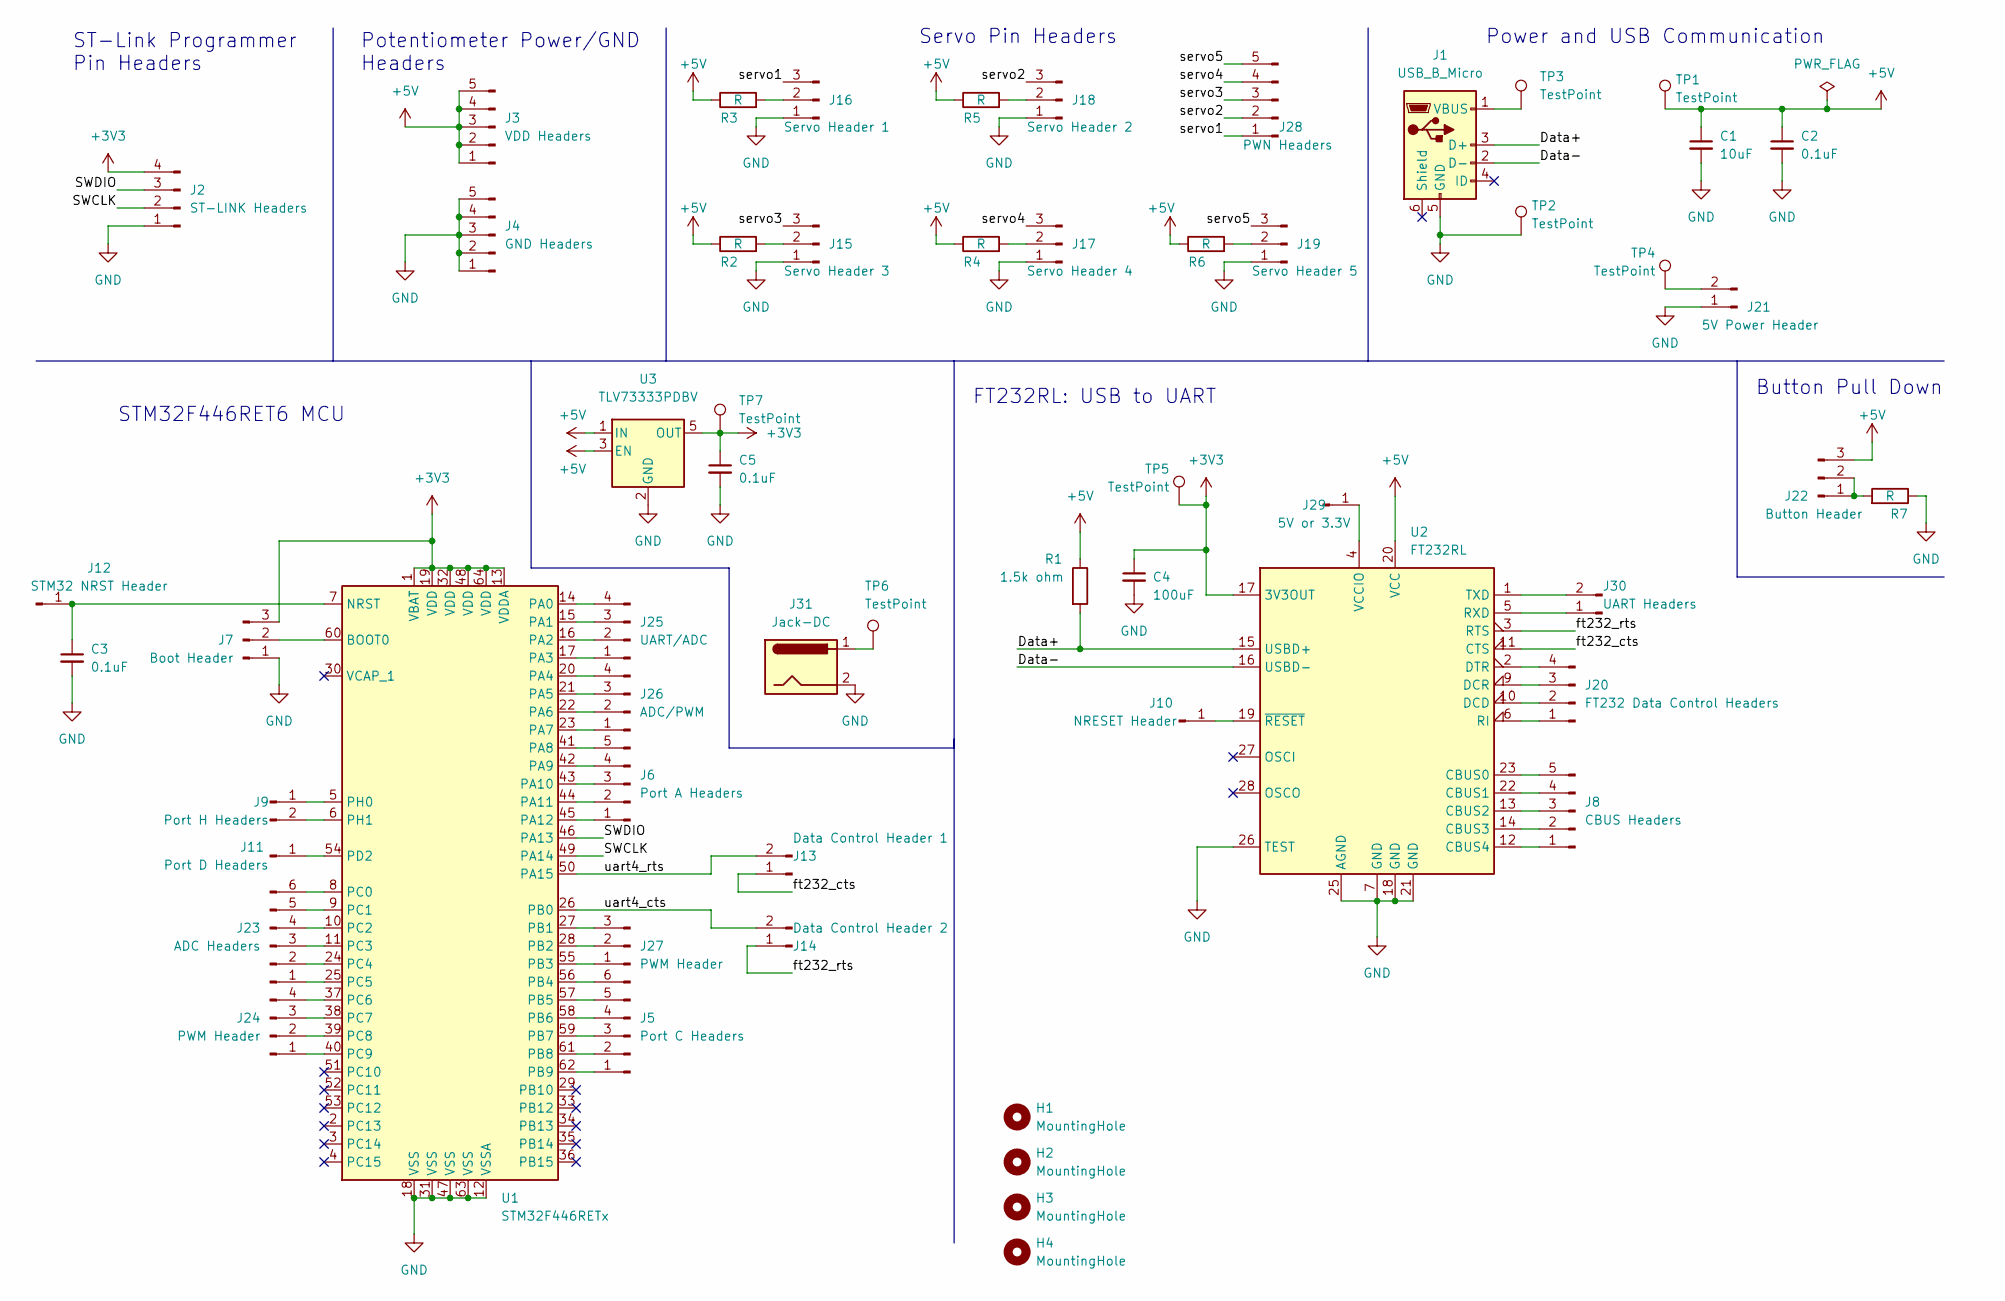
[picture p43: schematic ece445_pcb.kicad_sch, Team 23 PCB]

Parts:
C1: 10uF; C_0805_2012Metric_Pad1.18x1.45mm_HandSolder
C2, C3, C5: 0.1uF; C_0805_2012Metric_Pad1.18x1.45mm_HandSolder
C4: 100uF; C_0805_2012Metric_Pad1.18x1.45mm_HandSolder
H1, H2, H3, H4: MountingHole; MountingHole_3.2mm_M3
J1: USB_B_Micro; USB_Micro-B_Molex-105133-0031
J2: ST-LINK Headers; PinHeader_1x04_P2.54mm_Vertical
J3: VDD Headers; PinHeader_1x05_P2.54mm_Vertical
J4: GND Headers; PinHeader_1x05_P2.54mm_Vertical
J5: Port C Headers; PinHeader_1x06_P2.54mm_Vertical
J6: Port A Headers; PinHeader_1x05_P2.54mm_Vertical
J7: Boot Header; PinHeader_1x03_P2.54mm_Vertical
J8: CBUS Headers; PinHeader_1x05_P2.54mm_Vertical
J9: Port H Headers; PinHeader_1x02_P2.54mm_Vertical
J10: NRESET Header; PinHeader_1x01_P2.54mm_Vertical
J11: Port D Headers; PinHeader_1x01_P2.54mm_Vertical
J12: STM32 NRST Header; PinHeader_1x01_P2.54mm_Vertical
J13: Data Control Header 1; PinHeader_1x02_P2.54mm_Vertical
J14: Data Control Header 2; PinHeader_1x02_P2.54mm_Vertical
J15: Servo Header 3; PinHeader_1x03_P2.54mm_Vertical
J16: Servo Header 1; PinHeader_1x03_P2.54mm_Vertical
J17: Servo Header 4; PinHeader_1x03_P2.54mm_Vertical
J18: Servo Header 2; PinHeader_1x03_P2.54mm_Vertical
J19: Servo Header 5; PinHeader_1x03_P2.54mm_Vertical
J20: FT232 Data Control Headers; PinHeader_1x04_P2.54mm_Vertical
J21: 5V Power Header; PinHeader_1x02_P2.54mm_Vertical
J22: Button Header; PinHeader_1x03_P2.54mm_Vertical
J23: ADC Headers; PinHeader_1x06_P2.54mm_Vertical
J24: PWM Header; PinHeader_1x04_P2.54mm_Vertical
J25: UART/ADC; PinHeader_1x04_P2.54mm_Vertical
J26: ADC/PWM; PinHeader_1x04_P2.54mm_Vertical
J27: PWM Header; PinHeader_1x03_P2.54mm_Vertical
J28: PWN Headers; PinHeader_1x05_P2.54mm_Vertical
J29: 5V or 3.3V; PinHeader_1x01_P2.54mm_Vertical
J30: UART Headers; PinHeader_1x02_P2.54mm_Vertical
J31: Jack-DC; BarrelJack_Wuerth_6941xx301002
R1: 1.5k ohm; R_0805_2012Metric_Pad1.20x1.40mm_HandSolder
R2, R3, R4, R5, R6, R7: R; R_Axial_DIN0207_L6.3mm_D2.5mm_P5.08mm_Vertical
TP1, TP2, TP3, TP4, TP5, TP6, TP7: TestPoint; TestPoint_Keystone_5019_Minature
U1: STM32F446RETx; LQFP-64_10x10mm_P0.5mm
U2: FT232RL; SSOP-28_5.3x10.2mm_P0.65mm
U3: TLV73333PDBV; SOT-23-5

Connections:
+3V3: C4.1, C5.1, J2.4, J7.3, TP5.1, TP7.1, U1.1 (VBAT), U1.13 (VDDA), U1.19 (VDD), U1.32 (VDD), U1.48 (VDD), U1.64 (VDD), U2.17 (3V3OUT), U3.5 (OUT)
+5V: C1.1, C2.1, J3.1, J3.2, J3.3, J3.4, J3.5, J22.3, R1.1, R2.1, R3.1, R4.1, R5.1, R6.1, TP1.1, U2.20 (VCC), U3.1 (IN), U3.3 (EN)
/Data+: J1.3 (D+), R1.2, U2.15 (USBD+)
/Data-: J1.2 (D-), U2.16 (USBD-)
/SWCLK: J2.2, U1.49 (PA14)
/SWDIO: J2.3, U1.46 (PA13)
/ft232_cts: J13.1, U2.11 (CTS)
/ft232_rts: J14.1, U2.3 (RTS)
/servo1: J16.3, J28.1
/servo2: J18.3, J28.2
/servo3: J15.3, J28.3
/servo4: J17.3, J28.4
/servo5: J19.3, J28.5
/uart4_cts: J14.2, U1.26 (PB0)
/uart4_rts: J13.2, U1.50 (PA15)
GND: C1.2, C2.2, C3.2, C4.2, C5.2, J1.5 (GND), J2.1, J4.1, J4.2, J4.3, J4.4, J4.5, J7.1, J15.1, J16.1, J17.1, J18.1, J19.1, J21.1, J31.2, R7.1, TP2.1, U1.12 (VSSA), U1.18 (VSS), U1.31 (VSS), U1.47 (VSS), U1.63 (VSS), U2.7 (GND), U2.18 (GND), U2.21 (GND), U2.25 (AGND), U2.26 (TEST), U3.2 (GND)
unnamed: C3.1, J12.1, U1.7 (NRST)
unnamed: J1.1 (VBUS), TP3.1
unnamed: J5.1, U1.62 (PB9)
unnamed: J5.2, U1.61 (PB8)
unnamed: J5.3, U1.59 (PB7)
unnamed: J5.4, U1.58 (PB6)
unnamed: J5.5, U1.57 (PB5)
unnamed: J5.6, U1.56 (PB4)
unnamed: J6.1, U1.45 (PA12)
unnamed: J6.2, U1.44 (PA11)
unnamed: J6.3, U1.43 (PA10)
unnamed: J6.4, U1.42 (PA9)
unnamed: J6.5, U1.41 (PA8)
unnamed: J7.2, U1.60 (BOOT0)
unnamed: J8.1, U2.12 (CBUS4)
unnamed: J8.2, U2.14 (CBUS3)
unnamed: J8.3, U2.13 (CBUS2)
unnamed: J8.4, U2.22 (CBUS1)
unnamed: J8.5, U2.23 (CBUS0)
unnamed: J9.1, U1.5 (PH0)
unnamed: J9.2, U1.6 (PH1)
unnamed: J10.1, U2.19 (~RESET)
unnamed: J11.1, U1.54 (PD2)
unnamed: J15.2, R2.2
unnamed: J16.2, R3.2
unnamed: J17.2, R4.2
unnamed: J18.2, R5.2
unnamed: J19.2, R6.2
unnamed: J20.1, U2.6 (RI)
unnamed: J20.2, U2.10 (DCD)
unnamed: J20.3, U2.9 (DCR)
unnamed: J20.4, U2.2 (DTR)
unnamed: J21.2, TP4.1
unnamed: J22.1, J22.2, R7.2
unnamed: J23.1, U1.25 (PC5)
unnamed: J23.2, U1.24 (PC4)
unnamed: J23.3, U1.11 (PC3)
unnamed: J23.4, U1.10 (PC2)
unnamed: J23.5, U1.9 (PC1)
unnamed: J23.6, U1.8 (PC0)
unnamed: J24.1, U1.40 (PC9)
unnamed: J24.2, U1.39 (PC8)
unnamed: J24.3, U1.38 (PC7)
unnamed: J24.4, U1.37 (PC6)
unnamed: J25.1, U1.17 (PA3)
unnamed: J25.2, U1.16 (PA2)
unnamed: J25.3, U1.15 (PA1)
unnamed: J25.4, U1.14 (PA0)
unnamed: J26.1, U1.23 (PA7)
unnamed: J26.2, U1.22 (PA6)
unnamed: J26.3, U1.21 (PA5)
unnamed: J26.4, U1.20 (PA4)
unnamed: J27.1, U1.55 (PB3)
unnamed: J27.2, U1.28 (PB2)
unnamed: J27.3, U1.27 (PB1)
unnamed: J29.1, U2.4 (VCCIO)
unnamed: J30.1, U2.5 (RXD)
unnamed: J30.2, U2.1 (TXD)
unnamed: J31.1, TP6.1

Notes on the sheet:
FT232RL: USB to UART
Servo Pin Headers
Button Pull Down
Potentiometer Power/GND Headers
ST-Link Programmer Pin Headers
Power and USB Communication
STM32F446RET6 MCU

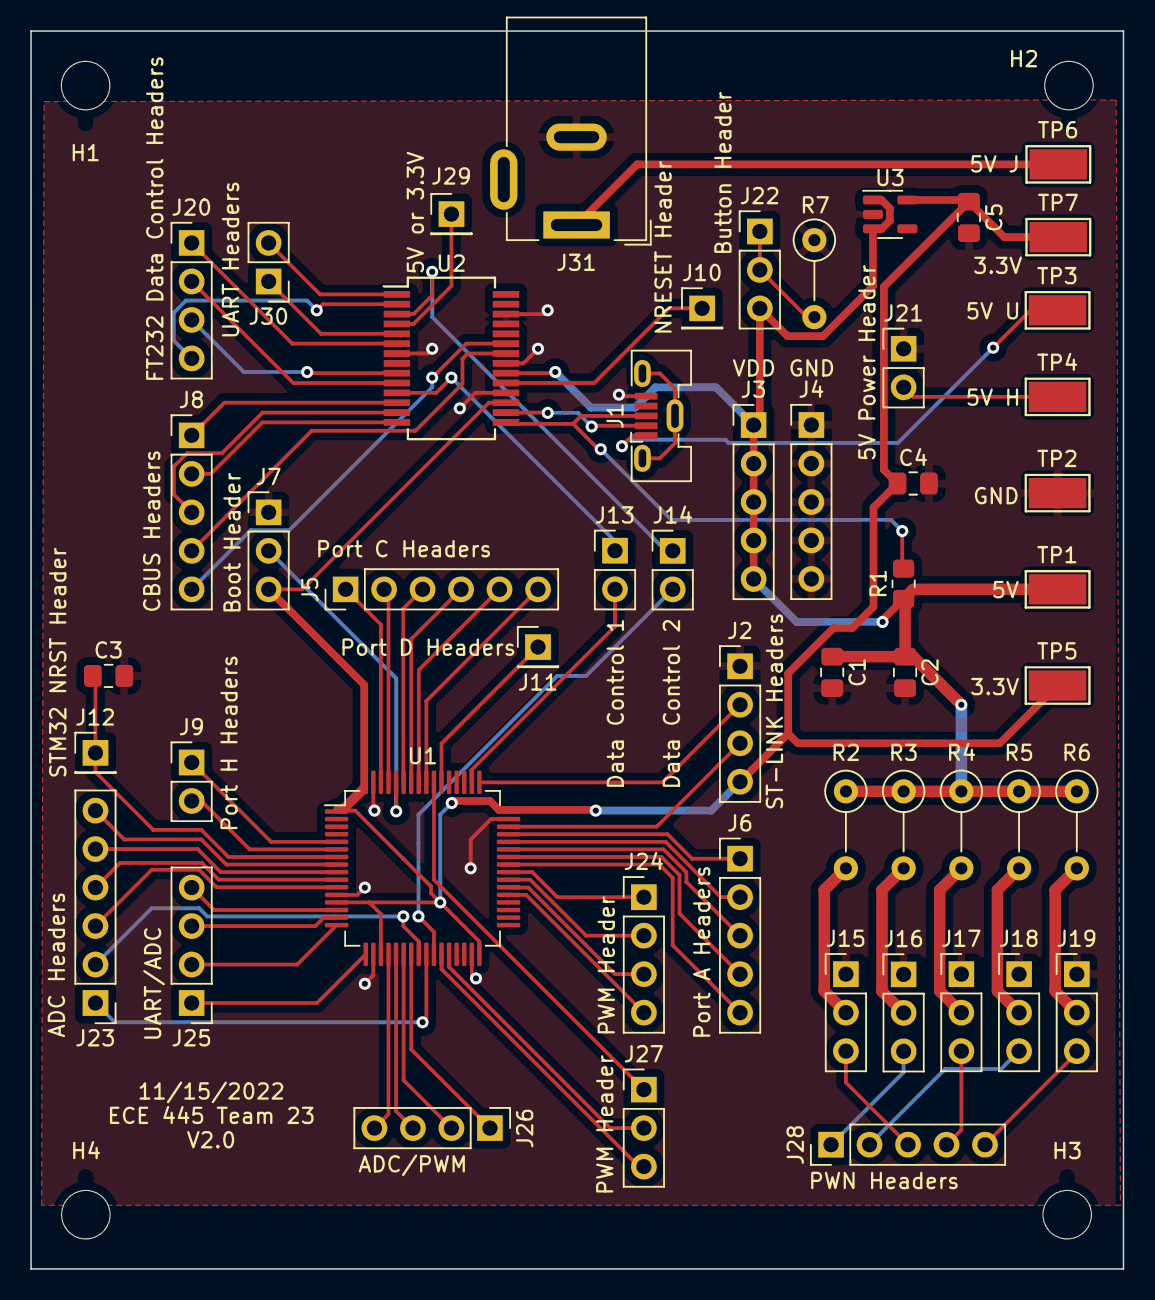
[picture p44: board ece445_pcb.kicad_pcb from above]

Board: 2 copper layers, 72.1 x 81.7 mm, 57 parts (0 on the bottom side), 75 nets.

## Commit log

2022-12-07 add datasheet to servo datasheet
2022-12-09 uploaded mechanical design
    [Base.stl, Finger Tip.ipt, Finger Tip.stl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]
2022-12-09 Uploaded the PCB files
    [ece445_pcb.kicad_pcb, ece445_pcb.kicad_sch]
